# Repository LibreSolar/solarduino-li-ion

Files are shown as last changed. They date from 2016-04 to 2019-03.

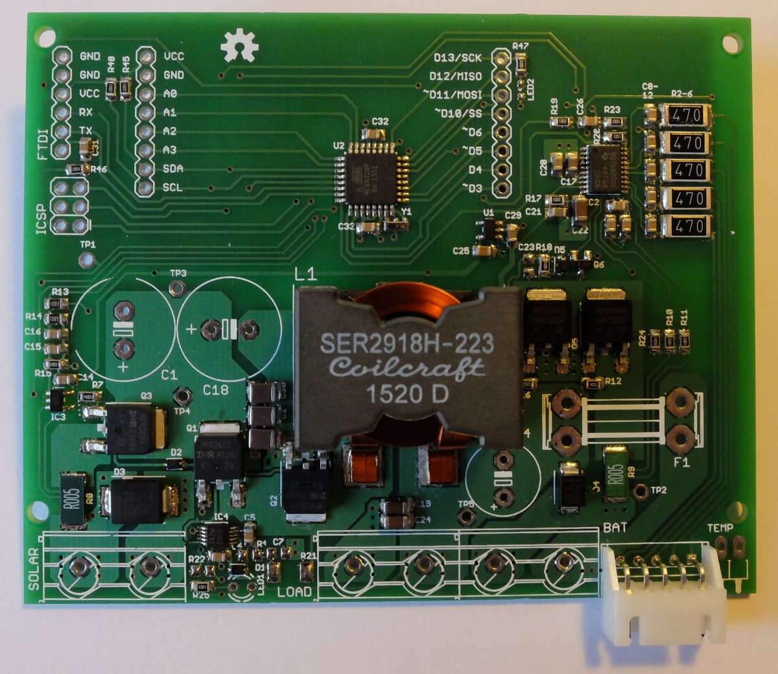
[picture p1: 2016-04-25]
DSCF9015_small.jpg

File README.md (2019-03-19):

# Solarduino Li-Ion
Solar charge controller with integrated 12 V Li-Ion BMS

**Remark:** This charge controller is not maintained anymore and firmware + hardware might contain serious bugs. Use at your own risk!

Features so far: 

- 12 V LiFePO4 BMS (4 cells)
- 8A MPPT charger
- 50V max PV input
- 16V max. DCDC output = battery voltage
- Arduino-compatible (ATmega 328P used)
- Expandable via break-out of unused ports to standard 2.54 pin-pitch headers (e.g. used for display, communication like CAN/RS485, etc.)

Built-in protection:
- Overvoltage
- Undervoltage
- Overcurrent
- Overtemperature (via software)
- PV short circuit
- PV reverse polarity (via diode)
- Battery reverse polarity (destructive, fuse is blown)

# Firmware
The last version of the firmware based on Arduino can be found in the firmware directory.

# Known issues
- The current measurement using the INA168 does not work properly. The output should not be directly connected to the ADC, but should be buffed using an Op-amp in between.

# Roadmap
- My plan for the future is to separate the BMS system and the charge controller. Separate modules make the system more flexible. For a new, extended version of the BMS system see my other project here on github.
- A new version of the Solarduino charge controller will be capable of 12-24V and 12 A, thus just perfect for one large 60-cell PV panel in a 24V system.

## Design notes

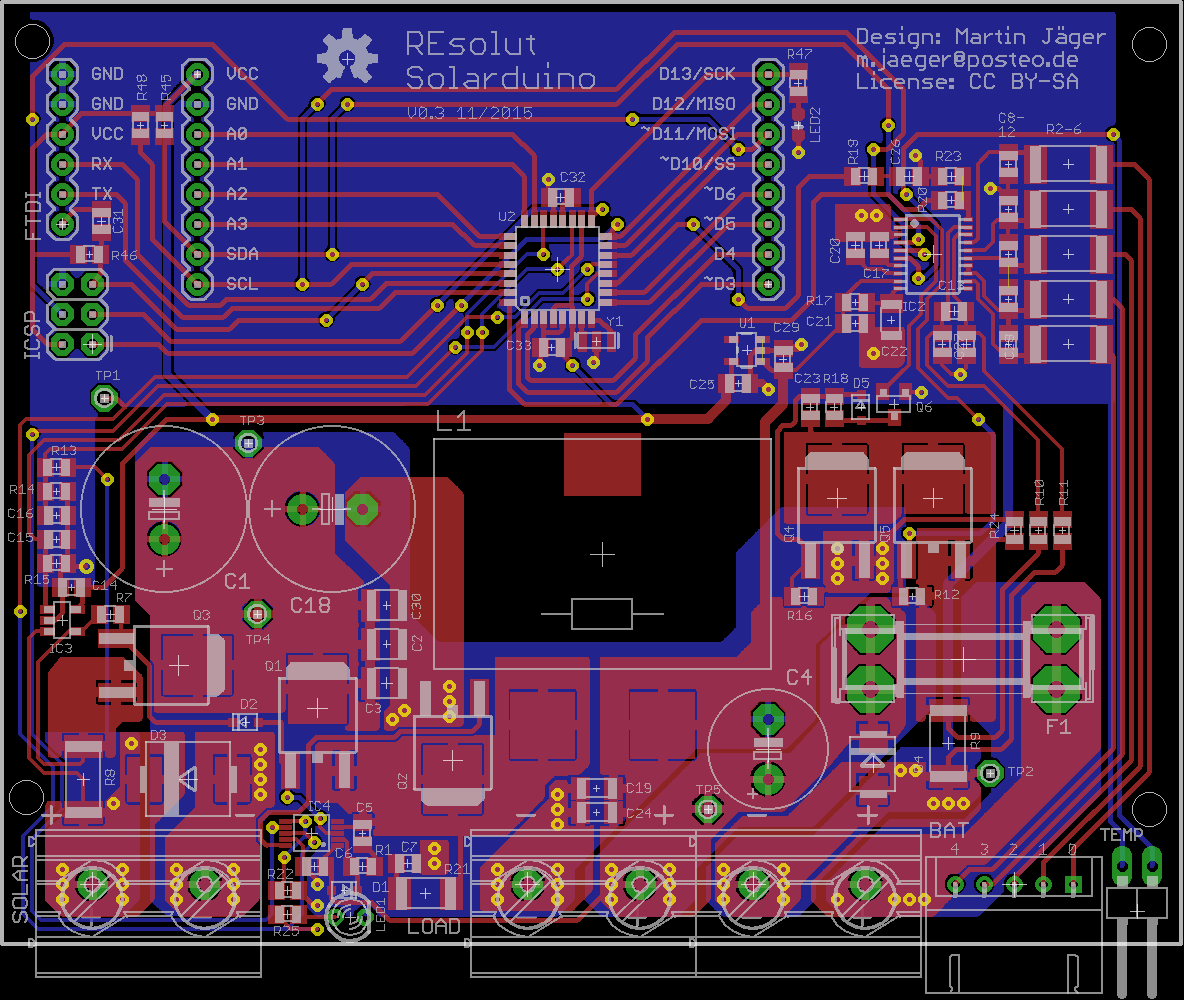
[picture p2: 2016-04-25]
Solarduino.png

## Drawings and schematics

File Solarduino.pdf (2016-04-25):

A

A

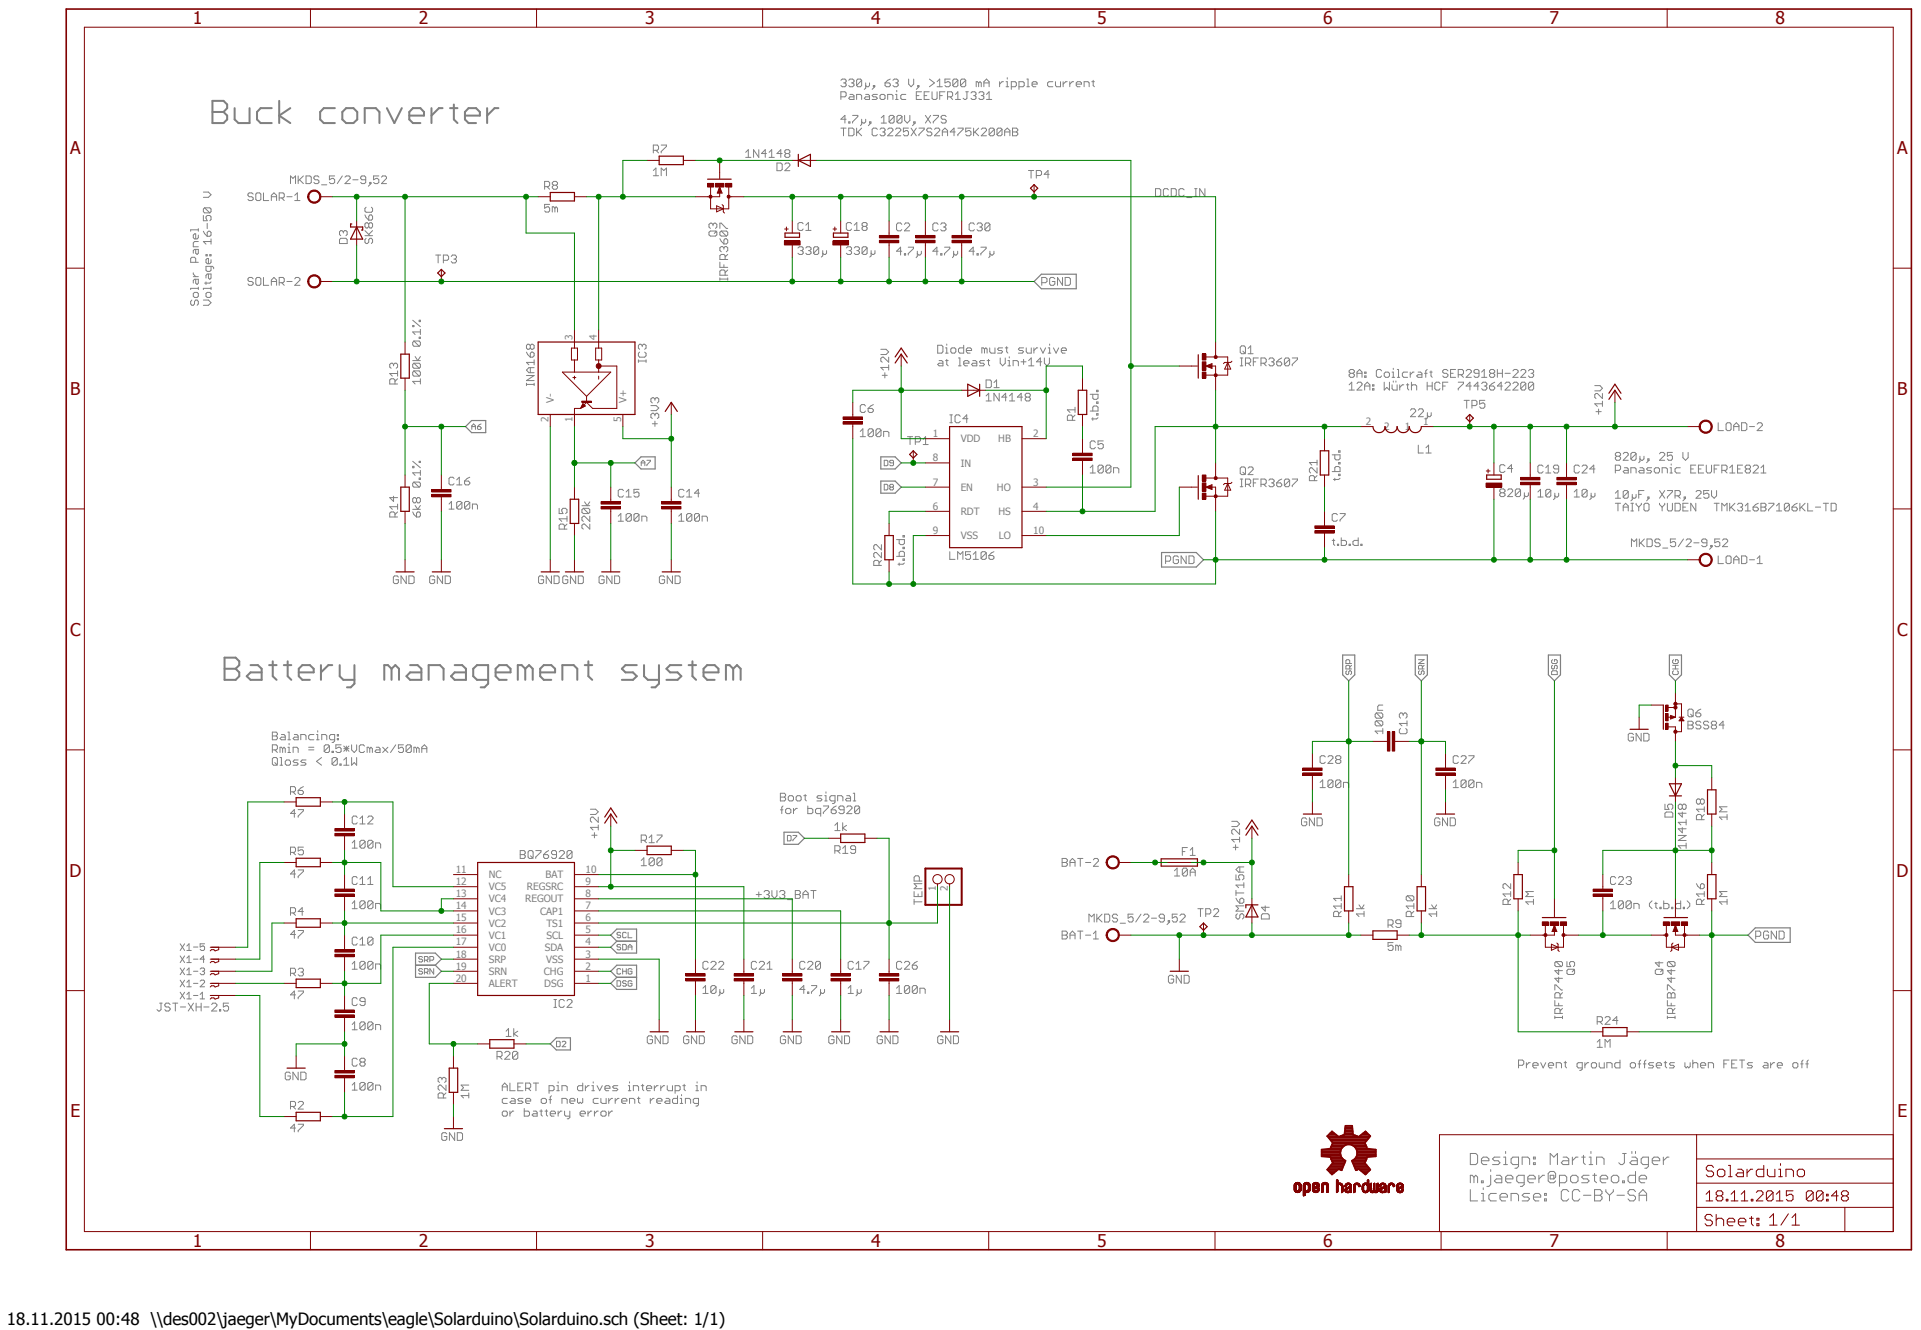
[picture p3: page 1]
DSG; 1 CHG; 2 VSS; 3 SDA; 4 SCL; 6 CAP1; 7 REGOUT; 8 REGSRC; 9 BAT; SRP 18; SRN 19; ALERT 20; VDD 1; 4 RDT 6; VSS 9

18.11.2015 00:48 \\des002\jaeger\MyDocuments\eagle\Solarduino\Solarduino.sch (Sheet: 1/1)

A

A

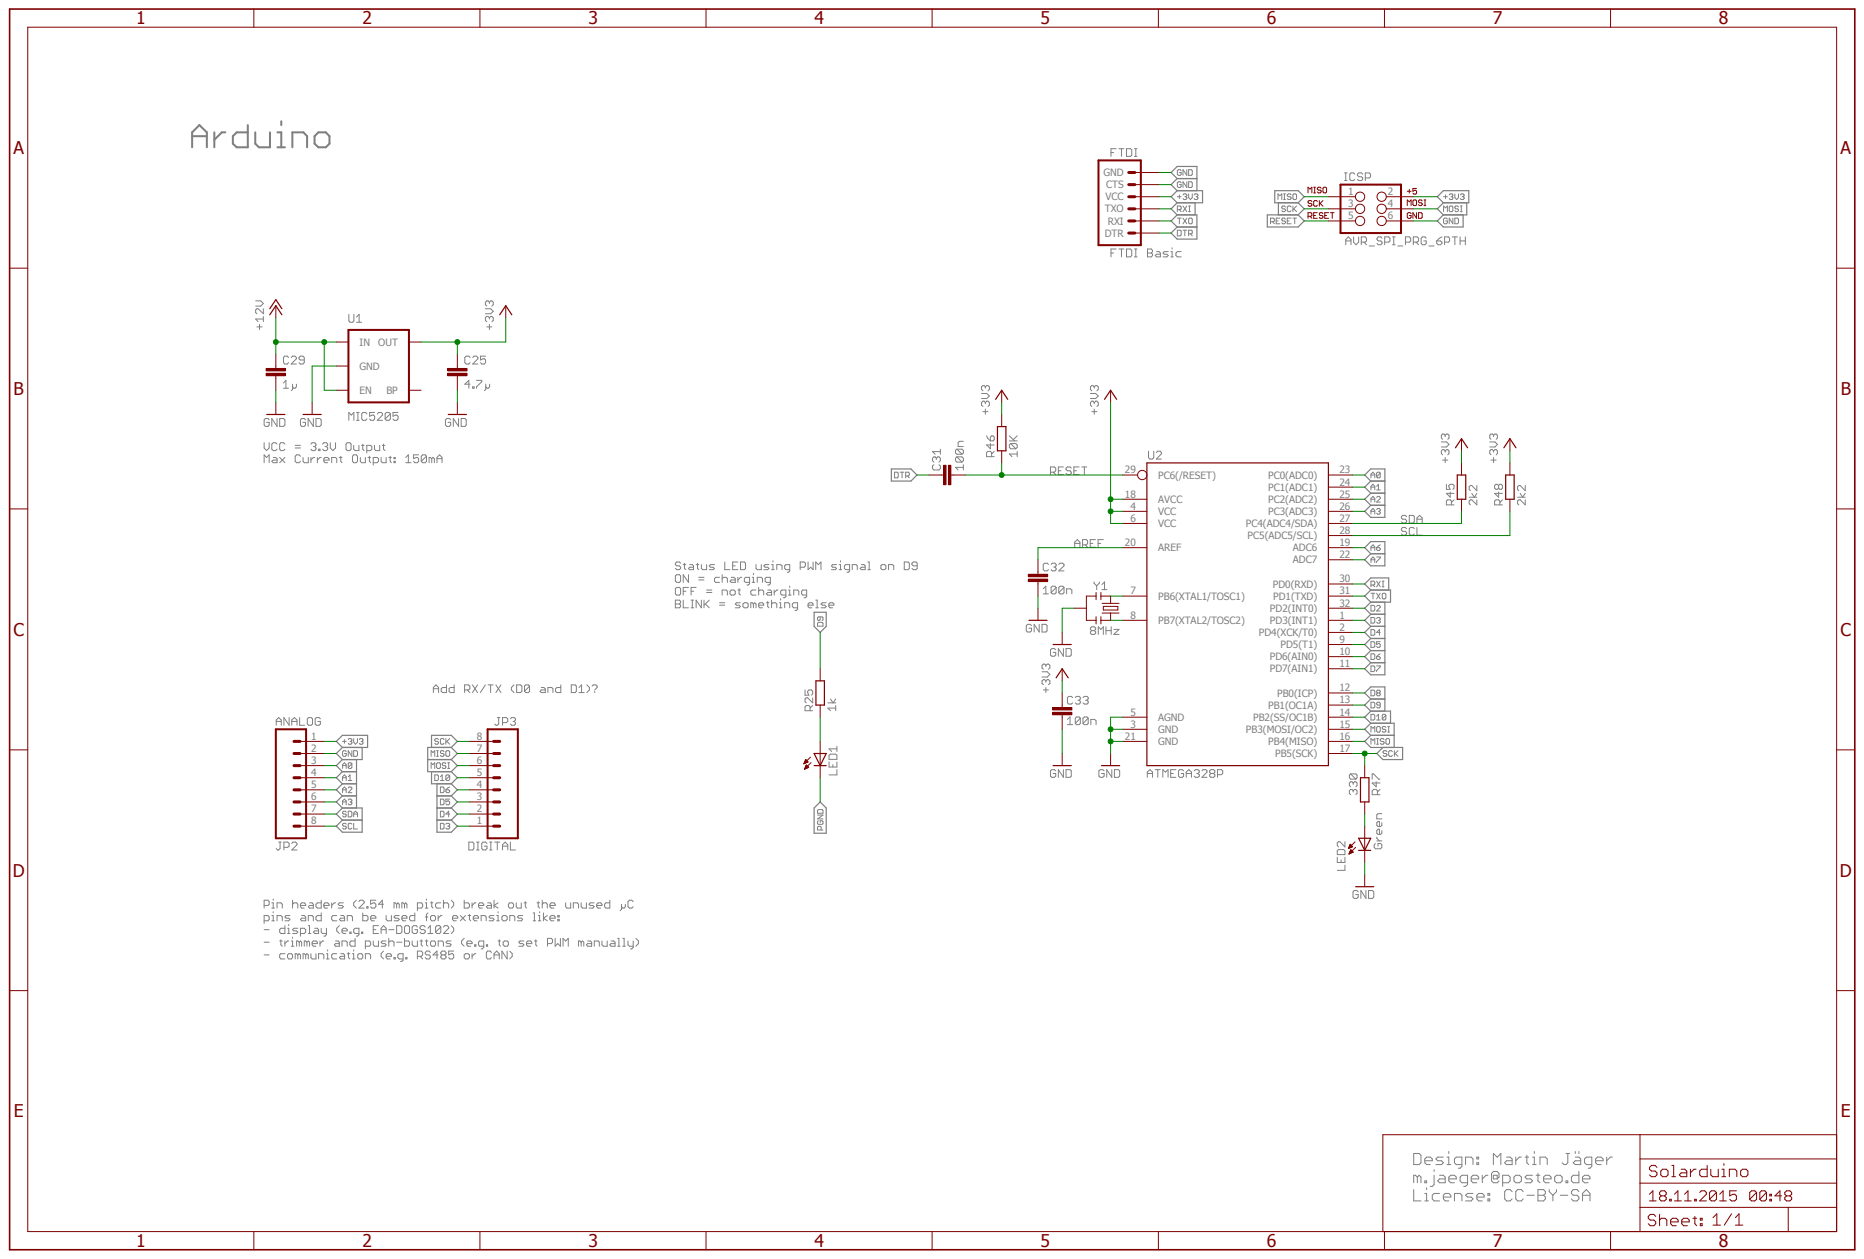
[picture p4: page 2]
PB5(SCK); PB7(XTAL2/TOSC2); PB6(XTAL1/TOSC1); GND; 3 GND 21; VCC; AGND; AREF 20; AVCC 18; PB4(MISO); 16 PB3(MOSI/OC2); 13 PB0(ICP); PD7(AIN1); 11 PD6(AIN0); 9 PD4(XCK/T0); 2 PD3(INT1); 1 PD2(INT0); 32 PD1(TXD); 31 PD0(RXD); ADC7; 22 ADC6; 19 PC5(ADC5/SCL); 28 PC4(ADC4/SDA); 27 PC3(ADC3); 26 PC2(ADC2); 25 PC1(ADC1); 24 PC0(ADC0); 23 PC6(/RESET) 29; DTR; RXI; TXO; CTS; OUT

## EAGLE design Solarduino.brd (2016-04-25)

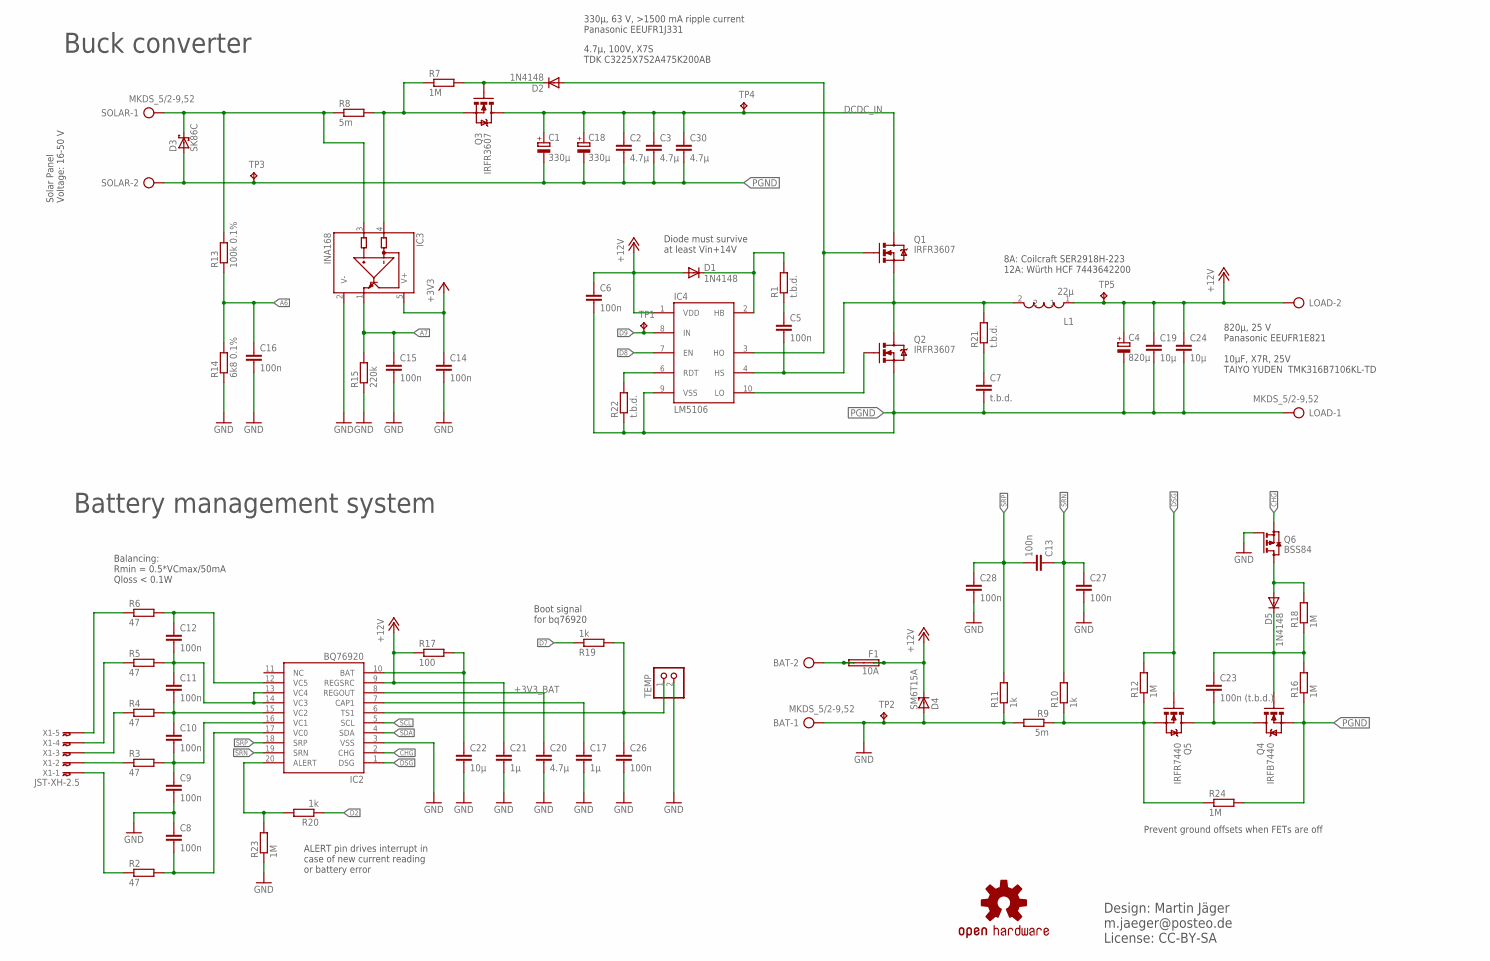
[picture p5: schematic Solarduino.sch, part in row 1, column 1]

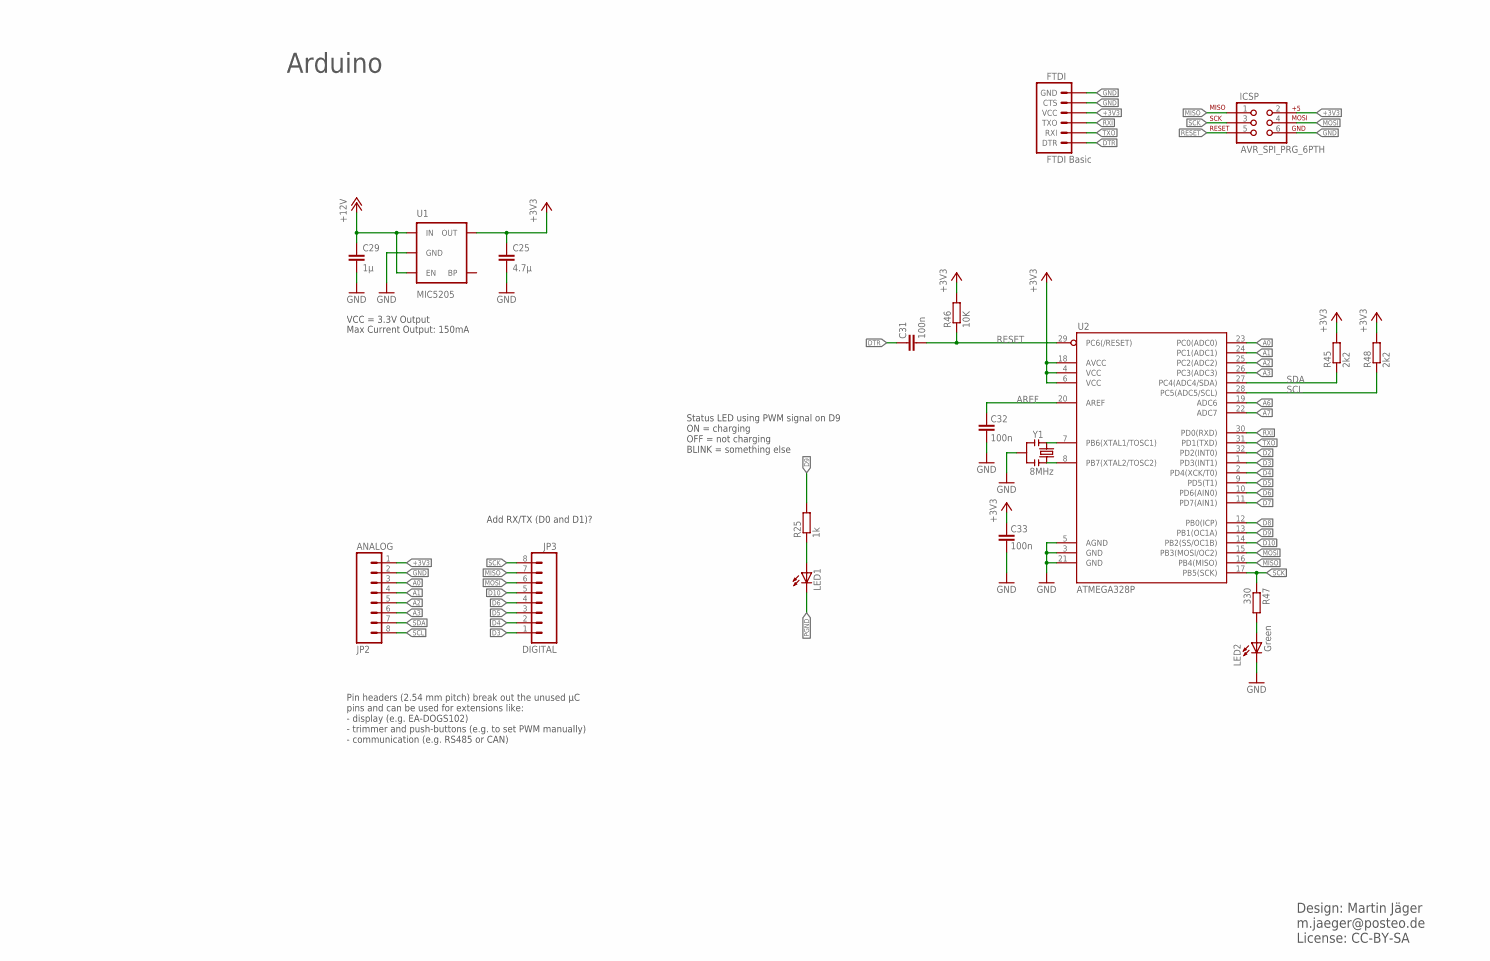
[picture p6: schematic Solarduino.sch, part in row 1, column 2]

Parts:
BAT: MKDS_5/2-9,52; MKDS_5/2-952
C1, C18: 330µ; E5-13; MPN EEUFR1J331B
C2, C3, C30: 4.7µ; C1210; MPN C3225X7S2A475K200AB
C4: 820µ; E5-10,5; MPN EEUFR1E821B
C5, C6, C8, C9, C10, C11, C12, C13, C14, C15, C16, C26, C27, C28, C31, C32: 100n; C0805; MPN 08055C104KAT2A
C7: t.b.d.; C0805; MPN 08055C104KAT2A
C17, C21, C29: 1µ; C0805; MPN 08053C105KAT2A
C19, C22, C24: 10µ; C1206; MPN TMK316B7106KL-TD
C20, C25: 4.7µ; C0805; MPN 0805YC475KAT2A
C23: 100n (t.b.d.); C0805; MPN 08055C104KAT2A
C33: 100n; C0805; MPN 08055C104JAT2A
D1, D2, D5: 1N4148; SOD323-R; MPN 1N4148WS-E3-08
D3: SK86C; SMC; MPN SK56C
D4: SM6T15A; SMB; MPN P6SMBJ15A
F1: 10A; SHK20Q
FTDI: FTDI Basic; 1X06; MPN 2212S-06SG-85
IC2: BQ76920; TSSOP20
IC3: INA168; SOT23-5; MPN INA168NA/250.
IC4: LM5106; VSSOP10; MPN LM5106MM/NOPB
ICSP: AVR_SPI_PRG_6PTH; 2X3
JP2: ANALOG; 1X08_ROUND
JP3: DIGITAL; 1X08_ROUND
L1: 22µ; WE-HCF_2818_7443643300; MPN SER2918H-223KL
LED1: LED3MM; MPN MCL034GD
LED2: Green; 0603-LED-ALT1; MPN MCL034GD
LOAD: MKDS_5/2-9,52; MKDS_5/2-952
N1: OSHW-LOGOM; OSHW-LOGO-M
Q1, Q2, Q3: IRFR3607; DPAK; MPN IRFR3607PBF
Q4: IRFB7440; DPAK; MPN IRFR7440TRPBF
Q5: IRFR7440; DPAK; MPN IRFR7440TRPBF
Q6: BSS84; SOT23; MPN BSS84-7-F
R1, R22: t.b.d.; R0805; MPN CR0805-FX-1001ELF
R2, R3, R4, R5, R6: 47; R2512; MPN MCHP122WF470JT4E
R7, R12, R16, R18, R23, R24: 1M; R0805; MPN CR0805-FX-1004ELF.
R8, R9: 5m; R2512; MPN CRF2512-FX-R005ELF
R10, R11, R19, R20, R25: 1k; R0805; MPN CR0805-FX-1001ELF
R13: 100k 0.1%; R0805; MPN ERA6AEB104V
R14: 6k8 0.1%; R0805; MPN ERA6AEB682V
R15: 220k; R0805; MPN CHV0805-FX-2203ELF
R17: 100; R0805; MPN CR0805-FX-1000-ELF
R21: t.b.d.; R2010; MPN CRM2010-JW-2R2ELF
R45, R48: 2k2; R0805; MPN CR0805-FX-1001ELF
R46: 10K; R0805; MPN CR0805-FX-1002ELF
R47: 330; R0805; MPN CR0805-FX-3300ELF
SOLAR: MKDS_5/2-9,52; MKDS_5/2-952
TEMP: PINHD-1X2/90; 1X02/90; MPN MC34745
TP1, TP2, TP3, TP4, TP5: TPPAD1-13; P1-13
U1: MIC5205; SOT23-5; MPN MIC5205-3.3YM5 TR
U2: ATMEGA328P; TQFP32-08; MPN ATMEGA328P-AU
X1: JST-XH-2.5; S5B-XH; MPN S5B-XH-A (LF)(SN)
Y1: 8MHz; RESONATOR-SMD; MPN CSTCE8M00G55-R0

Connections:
+3V3: C14.1, C25.1, C33.2, FTDI.4 (VCC), IC3.5 (V+), ICSP.2, JP2.1, R45.2, R46.2, R48.2, U1.5 (OUT), U2.4 (VCC), U2.6 (VCC), U2.18 (AVCC)
+3V3_BAT: C20.1, IC2.8 (REGOUT)
+12V: C4.+, C6.1, C19.1, C21.1, C24.1, C29.1, D1.A, D4.C, F1.1A, F1.1B, IC2.9 (REGSRC), IC4.1 (VDD), L1.1, LOAD.2, R17.1, TP5.TP, U1.1 (IN), U1.3 (EN)
A0: JP2.3, U2.23 (PC0(ADC0))
A1: JP2.4, U2.24 (PC1(ADC1))
A2: JP2.5, U2.25 (PC2(ADC2))
A3: JP2.6, U2.26 (PC3(ADC3))
A6: C16.1, R13.1, R14.2, U2.19 (ADC6)
A7: C15.1, IC3.1 (OUT), R15.2, U2.22 (ADC7)
ALERT: IC2.20 (ALERT), R20.2, R23.2
AREF: C32.2, U2.20 (AREF)
BAT+: BAT.2, F1.2A, F1.2B
CHG: IC2.2 (CHG), Q6.2 (S)
D2: R20.1, U2.32 (PD2(INT0))
D3: JP3.1, U2.1 (PD3(INT1))
D4: JP3.2, U2.2 (PD4(XCK/T0))
D5: JP3.3, U2.9 (PD5(T1))
D6: JP3.4, U2.10 (PD6(AIN0))
D7: R19.1, U2.11 (PD7(AIN1))
D8: IC4.7 (EN), U2.12 (PB0(ICP))
D9: IC4.8 (IN), R25.2, TP1.TP, U2.13 (PB1(OC1A))
D10: JP3.5, U2.14 (PB2(SS/OC1B))
DCDC_IN: C1.+, C2.1, C3.1, C18.+, C30.1, Q1.4 (D), Q3.4 (D), TP4.TP
DSG: IC2.1 (DSG), Q5.1 (G), R12.2
DTR: C31.2, FTDI.1 (DTR)
D_LS: C5.2, IC4.4 (HS), L1.2, Q1.3 (S), Q2.4 (D), R21.2
GND: BAT.1, C8.1, C9.2, C14.2, C15.2, C16.2, C17.2, C20.2, C21.2, C22.2, C25.2, C26.2, C27.2, C28.2, C29.2, C32.1, C33.1, D4.A, FTDI.5 (CTS), FTDI.6 (GND), IC2.3 (VSS), IC3.2 (V-), ICSP.6, JP2.2, LED2.C, Q6.1 (G), R9.2, R11.1, R14.1, R15.1, R23.1, TEMP.2, TP2.TP, U1.2 (GND), U2.3 (GND), U2.5 (AGND), U2.21 (GND), Y1.2
MISO: ICSP.1, JP3.7, U2.16 (PB4(MISO))
MOSI: ICSP.4, JP3.6, U2.15 (PB3(MOSI/OC2))
unnamed: IC3.4 (IN-), Q3.3 (S), R7.1, R8.2
unnamed: IC4.10 (LO), Q2.1 (G)
unnamed: LED2.A, R47.2
unnamed: D2.A, IC4.3 (HO), Q1.1 (G)
unnamed: D1.C, IC4.2 (HB), R1.2
unnamed: C23.1, D5.C, Q4.1 (G), R16.2, R18.1
unnamed: R3.1, X1.P$2
unnamed: C5.1, R1.1
unnamed: C22.1, IC2.10 (BAT), R17.2
unnamed: C10.1, C11.2, IC2.15 (VC2), R4.2
unnamed: C11.1, C12.2, IC2.13 (VC4), IC2.14 (VC3), R5.2
unnamed: R2.1, X1.P$1
unnamed: C12.1, IC2.12 (VC5), R6.2
unnamed: C8.2, IC2.17 (VC0), R2.2
unnamed: R4.1, X1.P$3
unnamed: C9.1, C10.2, IC2.16 (VC1), R3.2
unnamed: R5.1, X1.P$4
unnamed: D5.A, Q6.3 (D), R18.2
unnamed: D2.C, Q3.1 (G), R7.2
unnamed: U2.8 (PB7(XTAL2/TOSC2)), Y1.3
unnamed: U2.7 (PB6(XTAL1/TOSC1)), Y1.1
unnamed: Q5.3 (S), R9.1, R10.1, R12.1, R24.1
unnamed: C23.2, Q4.4 (D), Q5.4 (D)
unnamed: IC4.6 (RDT), R22.2
unnamed: R6.1, X1.P$5
unnamed: C17.1, IC2.7 (CAP1)
unnamed: C7.1, R21.1
unnamed: LED1.A, R25.1
NTC: C26.1, IC2.6 (TS1), R19.2, TEMP.1
PGND: C1.-, C2.2, C3.2, C4.-, C6.2, C7.2, C18.-, C19.2, C24.2, C30.2, D3.A, IC4.9 (VSS), LED1.K (C), LOAD.1, Q2.3 (S), Q4.3 (S), R16.1, R22.1, R24.2, SOLAR.2, TP3.TP
RESET: C31.1, ICSP.5, R46.1, U2.29 (PC6(/RESET))
RXI: FTDI.3 (TXO), U2.30 (PD0(RXD))
SCK: ICSP.3, JP3.8, R47.1, U2.17 (PB5(SCK))
SCL: IC2.5 (SCL), JP2.8, R48.1, U2.28 (PC5(ADC5/SCL))
SDA: IC2.4 (SDA), JP2.7, R45.1, U2.27 (PC4(ADC4/SDA))
SOLAR+: D3.C, IC3.3 (IN+), R8.1, R13.2, SOLAR.1
SRN: C13.1, C27.1, IC2.19 (SRN), R10.2
SRP: C13.2, C28.1, IC2.18 (SRP), R11.2
TXO: FTDI.2 (RXI), U2.31 (PD1(TXD))

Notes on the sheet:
330µ, 63 V, >1500 mA ripple current Panasonic EEUFR1J331
820µ, 25 V Panasonic EEUFR1E821 10µF, X7R, 25V TAIYO YUDEN TMK316B7106KL-TD
Balancing: Rmin = 0.5*VCmax/50mA Qloss < 0.1W
Solar Panel Voltage: 16-50 V
Diode must survive at least Vin+14V
Arduino
Add RX/TX (D0 and D1)?
Boot signal for bq76920
ALERT pin drives interrupt in case of new current reading or battery error
Max Current Output: 150mA
VCC = 3.3V Output
Pin headers (2.54 mm pitch) break out the unused µC pins and can be used for extensions like: - display (e.g. EA-DOGS102) - trimmer and push-buttons (e.g. to set PWM manually) - communication (e.g. RS485 or CAN)
Design: Martin Jäger m.jaeger@posteo.de License: CC-BY-SA
Buck converter
Battery management system
Prevent ground offsets when FETs are off
4.7µ, 100V, X7S TDK C3225X7S2A475K200AB
Status LED using PWM signal on D9 ON = charging OFF = not charging BLINK = something else
8A: Coilcraft SER2918H-223 12A: Würth HCF 7443642200

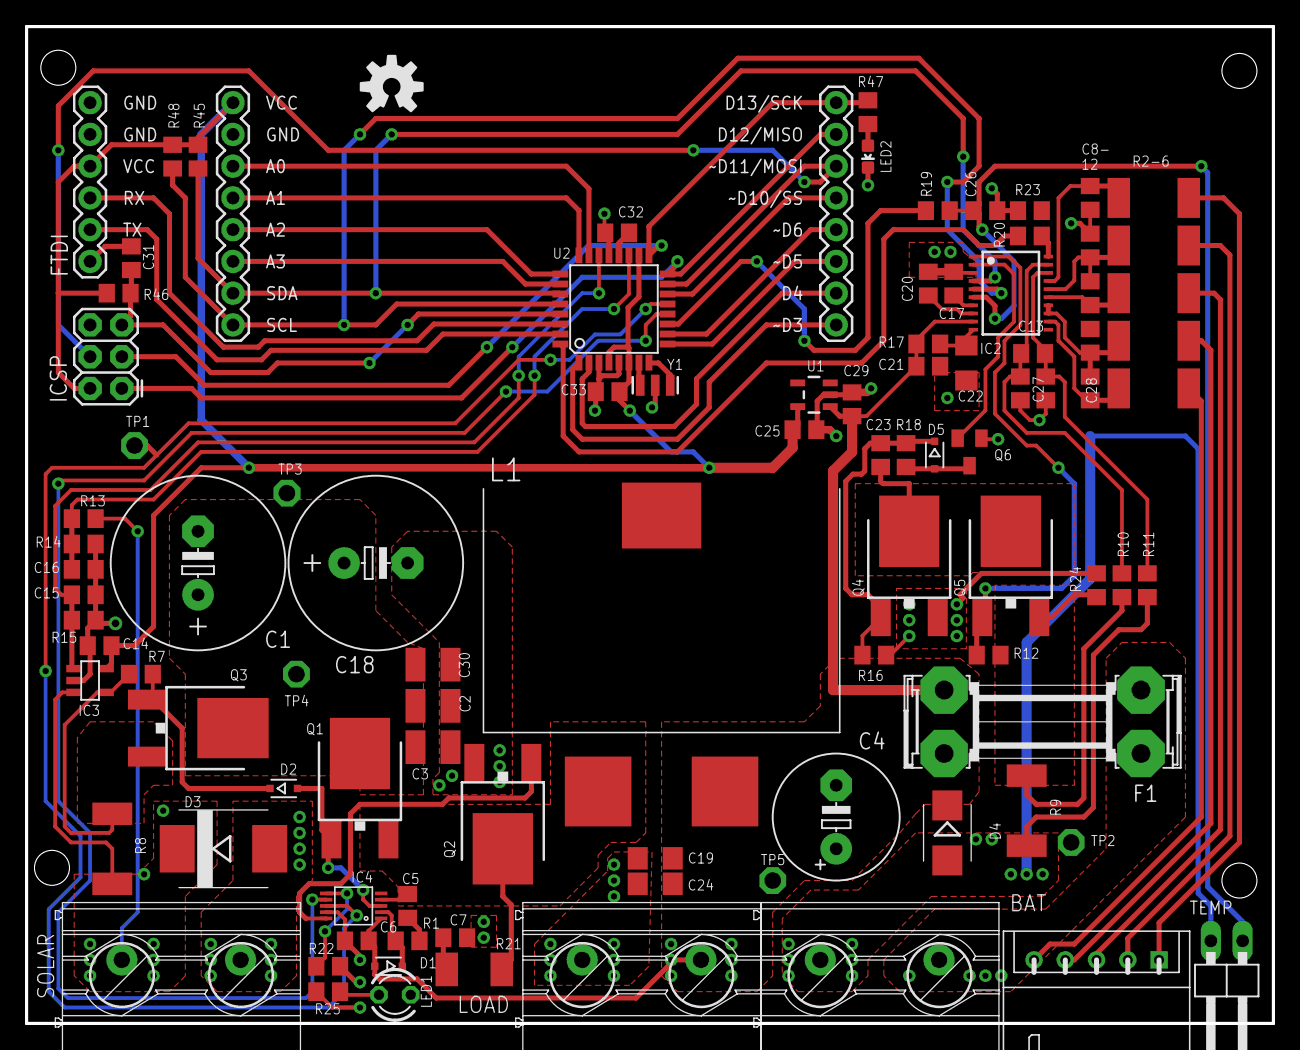
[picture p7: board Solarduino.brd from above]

Board: 2 copper layers, 99.7 x 79.7 mm, 98 parts (0 on the bottom side), 68 nets.

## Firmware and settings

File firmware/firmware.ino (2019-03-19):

/**
 *  Solarduino Software
 *  Martin Jäger, 2015
 *
 *  Solar charger and integrated LiFePO battery management system
 *  - uC: ATmega 328P with Arduino compatible pin useage
 *  - BMS IC: Texas Instruments bq76920
 *  - MPPT solar charger: Buck converter, max. 8A output current
 *
 *  
 */

//----------------------------------------------------------------------------
// includes

#include <Arduino.h>
#include <Wire.h>     // I2C/TWI (for Battery Management IC)
#include <SPI.h>      // SPI (for Display)
#include "helper.h"   // helper functions

#include <bq769x0.h>    // Library for Texas Instruments bq76920 battery management IC

// Display
#include <dog_1701.h>
#include <font_16x32nums.h>
#include <font_6x8.h>
#include <font_8x16.h>
#include <font_8x8.h>

//----------------------------------------------------------------------------
// definitions

#define PWM_PIN 9           // PWM input of half bridge driver
#define PWM_ENABLE_PIN 8    // enable pin of half bridge driver
#define DISP_CS_PIN    10
#define DISP_CD_PIN    A1
#define DISP_RESET_PIN A0
#define SOLAR_VOLTAGE_PIN A6
#define SOLAR_CURRENT_PIN A7

#define BMS_ALERT_PIN 2     // attached to interrupt INT0
#define BMS_BOOT_PIN 7      // connected to TS1 input
#define BMS_I2C_ADDRESS 0x18

// DC/DC converter settings
//
// The PWM resolution (number of steps between 0 and 100%) is limited by the
// µC frequency and the used PWM mode
// 8 MHz µC frequency and 100 kHz PWM frequency: 80 steps
//
#define PWM_FREQUENCY 100 // kHz
#define PWM_RESOLUTION ((F_CPU/1000)/PWM_FREQUENCY)
#define PWM_MIN (60.0/100.0*PWM_RESOLUTION)     // defines maximum input voltage (D=Vout/Vin)
#define PWM_INC 1                             // PWM increment for MPP tracking

#define MIN_SOLAR_CURRENT 50  // mA    --> if lower, charger is switched off
#define SOLAR_VOLTAGE_OFFSET 2000 // mV  charging switched on if Vsolar > Vbat + offset

// misc
#define ON 1
#define OFF 0
#define NUM_AVG 10    // number of ADC values to read for averaging

#define TURN_ON_MOSFETS digitalWrite(PWM_ENABLE_PIN, HIGH)      // enable MOSFET driver
#define TURN_OFF_MOSFETS digitalWrite(PWM_ENABLE_PIN, LOW)      // disable MOSFET driver

#define CUTOFF_VOLTAGE_CHG 3550  // mV    recommended value for ECC 45 Ah: 3550
#define CUTOFF_VOLTAGE_DSG 3000  // mV    recommended value for ECC 45 Ah: 3000
#define MAX_CHG_CURRENT 8000  // mA       PCB maximum: 8 A

//----------------------------------------------------------------------------
// global variables

dog_1701 DOG;   // display object
bq769x0 BMS(bq76920, BMS_I2C_ADDRESS);    // battery management system object

int pwm_duty = 63;  // PWM duty cycle (= PWM_RESOLUTION - 1 for 100%)
int solar_voltage;      // mV
int solar_current;      // mA

long solar_voltage_total;
long solar_current_total;
int solar_voltage_readings[NUM_AVG];
int solar_current_readings[NUM_AVG];
int i_readings = 0;

unsigned int solar_power_prev = 0;   // unit: 1/100 W
unsigned int solar_power = 0;        // unit: 1/100 W
int pwm_delta = PWM_INC;    // variable used to modify pwm duty cycle for the MPPT algorithm

enum charger_states {STANDBY, CHG_CC, CHG_CV, BAT_ERROR, BALANCING};     // enumerated variable that holds state for charger state machine
int state = BAT_ERROR;


//----------------------------------------------------------------------------
void setup()
{
  Serial.begin(9600);  // start serial for output  

  int err = BMS.begin(BMS_ALERT_PIN, BMS_BOOT_PIN);

  // ToDo: Ensure that these settings are set even in case of initial communication error
  BMS.setTemperatureLimits(-20, 45, 0, 45);
  BMS.setShuntResistorValue(5);
  BMS.setShortCircuitProtection(14000, 200);  // delay in us
  BMS.setOvercurrentChargeProtection(8000, 200);  // delay in ms
  BMS.setOvercurrentDischargeProtection(8000, 320); // delay in ms
  BMS.setCellUndervoltageProtection(2600, 2); // delay in s
  BMS.setCellOvervoltageProtection(3650, 2);  // delay in s

  BMS.setBalancingThresholds(0, 3300, 20);  // minIdleTime_min, minCellV_mV, maxVoltageDiff_mV
  BMS.setIdleCurrentThreshold(100);
  BMS.enableAutoBalancing();
  BMS.enableDischarging();
/*
  if (err > 0) {
    enter_state(BAT_ERROR);
  }
  else {
    enter_state(STANDBY);
  }
  */
  //initPWM();
  // TEST BEGIN
  pinMode(PWM_PIN, OUTPUT);
  pinMode(PWM_ENABLE_PIN, OUTPUT);
  digitalWrite(PWM_ENABLE_PIN, HIGH);
  Serial.println("PWM PIN is now highg");
  // TEST END
  
  // display
  DOG.initialize(DISP_CS_PIN, 0, 0, DISP_CD_PIN, DISP_RESET_PIN, DOGS102); // 0,0 = Hardware SPI, EA DOGS102-6 (=102x64 dots)
  //DOG.initialize(DISP_CS_PIN, 11, 13, DISP_CD_PIN, DISP_RESET_PIN, DOGS102); // 0,0 = Hardware SPI, EA DOGS102-6 (=102x64 dots)
  DOG.view(VIEW_BOTTOM);  //default viewing direction

  // initialize variables with zeros
  for (int i = 0; i < NUM_AVG; i++) {
    solar_voltage_readings[i] = 0;
    solar_current_readings[i] = 0;
  }
}

//----------------------------------------------------------------------------
// Sets Timer1 to run PWM output at Arduino pin 9
// 
void initPWM()
{
  // PWM_PIN must be pin 9 (OC1A of ATmega328P)
  pinMode(PWM_PIN, OUTPUT);
  pinMode(PWM_ENABLE_PIN, OUTPUT);

  // set mode 14: Fast PWM, TOP stored in ICR1
  TCCR1A = _BV(WGM11);
  TCCR1B = _BV(WGM13) | _BV(WGM12);
  
  // no prescaling
  TCCR1B |= _BV(CS10);

  // disable interrupts for 16-bit register access
  unsigned char sreg;  
  sreg = SREG;  // Save global interrupt flag
  cli();        // Disable interrupts

  // set TOP to define PWM frequency
  ICR1 = PWM_RESOLUTION - 1;
  
  SREG = sreg;  // Restore global interrupt flag

  Serial.print("PWM cycles: ");
  Serial.println(PWM_RESOLUTION);
}

//----------------------------------------------------------------------------
void loop()
{

  BMS.update();  // should be called at least every 250 ms

  update_solar_power();
  //state_machine();
  update_screen();
  
  //print_status();
  
  //BMS.printRegisters();

  // TEST BEGIN
  //TURN_ON_MOSFETS;
  //enter_state(CHG_CC);
  // TEST END
  
  /*
  // PWM testing
  char incoming = 0; 
  if (Serial.available() > 0) {
    // read the incoming byte:
    incoming = Serial.read();

    if (incoming == '+') {
      pwm_duty++;
      set_pwm_duty();
    }
    else if (incoming == '-') {
      pwm_duty--;
      set_pwm_duty();
    }
    
    Serial.print("PWM: ");
    Serial.print(pwm_duty);
    Serial.print("      Solar Power [mA]: ");
    Serial.println(solar_power);
  }

*/
  delay(100);
}

// actions to be performed upon entering a state
void enter_state(int next_state)
{
  switch (next_state)
  {
    case STANDBY:
      Serial.println(F("Enter State: STANDBY"));
      TURN_OFF_MOSFETS; 
      if (BMS.enableDischarging() == false) {
        return;
      }
      break;
    case CHG_CC:
      Serial.println(F("Enter State: CHG_CC"));
      if (BMS.enableCharging() == true)
      {
        //pwm_duty = PWM_RESOLUTION * BMS.getBatteryVoltage() / solar_voltage + 1;  // start with proper PWM duty cycle
        pwm_delta = -PWM_INC;
        set_pwm_duty();
        TURN_ON_MOSFETS;
        Serial.println(F("OK, laden muesste jetzt laufen..."));
      }
      else {
        Serial.println("Laden nicht möglich!");
        return;   // charging not possible
      }
      break;
    case CHG_CV:
      Serial.println("Enter State: CHG_CV");
      // coming from CHG_CC --> DC/DC FETs already on and charging enabled
      break;
    case BAT_ERROR:
      Serial.println("Enter State: BAT_ERROR");
      TURN_OFF_MOSFETS;
      break;
    case BALANCING:
      Serial.println("Enter State: BALANCING");
      TURN_OFF_MOSFETS; 
      break;
    default:
      TURN_OFF_MOSFETS; 
      break;
  }
  state = next_state;
}

/*****************************************************************************
 *  Charger state machine
 *
 *  INIT       Initial state when system boots up. Checks communication to BMS
 *             and turns the CHG and DSG FETs on
 *  STANDBY    Battery can be discharged, but no charging power is available
 *             or battery is fully charged
 *  CHG_CC     Constant current (CC) charging with maximum current possible
 *             (MPPT algorithm is running)
 *  CHG_CV     Constant voltage (CV) charging at maximum cell voltage
 *  BAT_ERROR  An error occured. Charging disabled.
 *  BALANCING  After a period of no load in STANDBY state, balancing is 
 *             started. Goes back to STANDBY as soon as a load is detected.
 */
void state_machine()
{
  int err = 0;
  
  switch (state)
  {
    case STANDBY:
      if (BMS.checkStatus() == 0)
      {
        //Serial.println("Standby");
        if  ((solar_voltage > BMS.getBatteryVoltage() + SOLAR_VOLTAGE_OFFSET)) {      
          enter_state(CHG_CC);
        }
      }
      /*else if (BMS.balancingAllowed() == true)
      {
        enter_state(BALANCING);
      }*/
      break;
      
    case CHG_CC:
      if (BMS.checkStatus() == 0)
      {
        //Serial.println("CHG_CC state still alive");
        if (BMS.getMaxCellVoltage() > CUTOFF_VOLTAGE_CHG)
        {
          enter_state(CHG_CV);
        }/*
        else if (BMS.getBatteryCurrent() > MAX_CHG_CURRENT)
        {
          // increase PV voltage
          pwm_duty--;
          pwm_delta = -PWM_INC;
          set_pwm_duty();
          solar_power_prev = solar_power;
        }
        else // start MPPT
        {
          if (solar_power_prev > solar_power)
          {
            pwm_delta = -pwm_delta;
          }
          pwm_duty += pwm_delta;
          set_pwm_duty();
          solar_power_prev = solar_power;
        }*/      
      }
      else
      {
        enter_state(BAT_ERROR);
      }
      break;
      
    case CHG_CV:
      if (BMS.checkStatus() == 0)
      {
        if (solar_current < MIN_SOLAR_CURRENT)
        {
          enter_state(STANDBY);
          return;
        }
        else {
          if (BMS.getMaxCellVoltage() > CUTOFF_VOLTAGE_CHG)
          {
            // increase input voltage and decrease PV current
            pwm_duty--;
            set_pwm_duty();
          }
          else
          {
            pwm_duty++;
            set_pwm_duty();
          }
        }
      }
      else {
        enter_state(BAT_ERROR);
      }
      break;
      
    case BAT_ERROR:
      err = BMS.checkStatus();
      if (err == 0) {
        enter_state(STANDBY);
      }
      break;
      
    default:
      TURN_OFF_MOSFETS; 
      break;
  }
}

//----------------------------------------------------------------------------
void set_pwm_duty()
{
  if (pwm_duty >= PWM_RESOLUTION - 1)
  {
    pwm_duty = PWM_RESOLUTION - 2;            // 100% not possible because of charge pump
  }
  else if (pwm_duty < PWM_MIN)
  {       
    pwm_duty = PWM_MIN;
  }
  
  // disable interrupts for 16-bit register access
  unsigned char sreg = SREG;
  cli();

  // set
  OCR1A = pwm_duty;
  
  // restore global interrupt flag
  SREG = sreg;                  

  // Compare Output Mode: Fast PWM, non-inverting mode
  TCCR1A |= _BV(COM1A1);
  
  //Serial.print("PWM duty cycle: ");
  //Serial.println((pwm_duty+1.0)/(PWM_RESOLUTION) * 100.0);
}

//----------------------------------------------------------------------------
//create a sample sceen content
void update_screen(void)
{
  char str[20];
  char buf[20];
  
  DOG.clear();  //clear whole display
  //DOG.string(71,0,font_8x16,"DOGS");      //font size 8x16 first page         
  //DOG.rectangle(71,2,127,2,0x03);         //show small line (filled pattern = 0x03), to the left and right of 'DOGL128'            
  
  format_double(solar_voltage/1000.0, 2, buf, 20);
  sprintf(str, "Sol: %sV", buf);
  DOG.string(0,0,font_6x8, str);

  format_double(solar_current/1000.0, 2, buf, 20);
  sprintf(str, "%sA", buf);
  DOG.string(12*6,0,font_6x8, str);
  
  format_double(BMS.getBatteryVoltage()/1000.0, 2, buf, 20);
  sprintf(str, "Bat: %sV", buf);
  DOG.string(0,1,font_6x8, str);

  format_double(BMS.getBatteryCurrent()/1000.0, 2, buf, 20);
  sprintf(str, "%sA", buf);
  DOG.string(12*6,1,font_6x8, str);

  format_double(BMS.getTemperatureDegC(), 1, buf, 20);
  sprintf(str, "Temp: %s C", buf);
  DOG.string(0,2,font_6x8, str);
  
  format_double(solar_power/100.0, 2, buf, 20);
  sprintf(str, "Power: %s W", buf);
  DOG.string(0,3,font_6x8, str);
  
  format_double((pwm_duty+1.0)/(PWM_RESOLUTION) * 100.0, 2, buf, 20);
  sprintf(str, "PWM duty: %s %%", buf);
  DOG.string(0,4,font_6x8, str);
  
  DOG.string(0,5,font_6x8,"State:");
  switch (state)
  {
    case STANDBY:
      DOG.string(7*6,5,font_6x8,"Standby");
      break;
    case CHG_CC:
      DOG.string(7*6,5,font_6x8,"CC charge");
      break;
    case CHG_CV:
      DOG.string(7*6,5,font_6x8,"CV charge");
      break;
    case BAT_ERROR:
      byte sys_stat;
      sys_stat = BMS.checkStatus();
      if (sys_stat & B00100000)
        DOG.string(7*6,5,font_6x8,"XR Error");
      if (sys_stat & B00010000)
        DOG.string(7*6,5,font_6x8,"Alert Error");
      if (sys_stat & B00001000)
        DOG.string(7*6,5,font_6x8,"UV Error");
      if (sys_stat & B00000100)
        DOG.string(7*6,5,font_6x8,"OV Error");
      if (sys_stat & B00000010)
        DOG.string(7*6,5,font_6x8,"SCD Error");
      if (sys_stat & B00000001)
        DOG.string(7*6,5,font_6x8,"OCD Error");
      break;
    case BALANCING:
      DOG.string(7*6,5,font_6x8,"Balancing");
      break;    
  }

  format_double(BMS.getCellVoltage(1)/1000.0, 3, buf, 20);
  sprintf(str, "1:%sV", buf);
  DOG.string(0,6,font_6x8, str);

  format_double(BMS.getCellVoltage(2)/1000.0, 3, buf, 20);
  sprintf(str, "2:%sV", buf);
  DOG.string(51,6,font_6x8, str);
  
  format_double(BMS.getCellVoltage(3)/1000.0, 3, buf, 20);
  sprintf(str, "3:%sV", buf);
  DOG.string(0,7,font_6x8, str);

  format_double(BMS.getCellVoltage(5)/1000.0, 3, buf, 20);
  sprintf(str, "4:%sV", buf);
  DOG.string(51,7,font_6x8, str);
  
}

//----------------------------------------------------------------------------
// Print out current status of the system
void print_status(void)
{
  char str[20];
  char buf[20];
    
  format_double(solar_voltage/1000.0, 2, buf, 20);
  sprintf(str, "Sol: %sV ", buf);
  Serial.print(str);

  format_double(solar_current/1000.0, 2, buf, 20);
  sprintf(str, "%sA", buf);
  Serial.println(str);
  
  format_double(BMS.getBatteryVoltage()/1000.0, 2, buf, 20);
  sprintf(str, "Bat: %sV ", buf);
  Serial.print(str);

  format_double(BMS.getBatteryCurrent()/1000.0, 2, buf, 20);
  sprintf(str, "%sA", buf);
  Serial.println(str);

  format_double(BMS.getTemperatureDegC(), 1, buf, 20);
  sprintf(str, "Temp: %s °C", buf);
  Serial.println(str);
  
  format_double(solar_power/100.0, 2, buf, 20);
  sprintf(str, "Power: %s W", buf);
  Serial.println(str);
  
  format_double((pwm_duty+1.0)/(PWM_RESOLUTION) * 100.0, 2, buf, 20);
  sprintf(str, "PWM duty: %s %%", buf);
  Serial.println(str);
  
  Serial.print("State:");
  switch (state)
  {
    case STANDBY:
      Serial.println("Standby");
      break;
    case CHG_CC:
      Serial.println("CC charge");
      break;
    case CHG_CV:
      Serial.println("CV charge");
      break;
    case BAT_ERROR:
      byte sys_stat;
      sys_stat = BMS.checkStatus();
      if (sys_stat & B00100000)
        Serial.println("XR Error");
      if (sys_stat & B00010000)
        Serial.println("Alert Error");
      if (sys_stat & B00001000)
        Serial.println("UV Error");
      if (sys_stat & B00000100)
        Serial.println("OV Error");
      if (sys_stat & B00000010)
        Serial.println("SCD Error");
      if (sys_stat & B00000001)
        Serial.println("OCD Error");
      break;
    case BALANCING:
      Serial.println("Balancing");
      break;    
  }

  format_double(BMS.getCellVoltage(1)/1000.0, 3, buf, 20);
  sprintf(str, "1:%sV", buf);
  Serial.print(str);

  format_double(BMS.getCellVoltage(2)/1000.0, 3, buf, 20);
  sprintf(str, "  2:%sV", buf);
  Serial.print(str);
  
  format_double(BMS.getCellVoltage(3)/1000.0, 3, buf, 20);
  sprintf(str, "  3:%sV", buf);
  Serial.print(str);

  format_double(BMS.getCellVoltage(5)/1000.0, 3, buf, 20);
  sprintf(str, "  4:%sV", buf);
  Serial.println(str);
  
}

//----------------------------------------------------------------------------
int update_solar_power(void)
{
  int vcc;
  vcc = read_vcc();  // using internal reference voltage

  // subtract the last reading:
  solar_voltage_total -= solar_voltage_readings[i_readings];
  solar_current_total -= solar_current_readings[i_readings];

  // save new reading
  solar_voltage_readings[i_readings] = analogRead(SOLAR_VOLTAGE_PIN)/1023.0 * vcc * 106.8/6.8;  // mV
  
  // 220 kOhm resistor at INA168 --> gain 44
  // 5 mOhm shunt resistor
  solar_current_readings[i_readings] = analogRead(SOLAR_CURRENT_PIN)/1023.0 * vcc / 5.0 * 44;  // mA

  // add the reading to the total:
  solar_voltage_total += solar_voltage_readings[i_readings];
  solar_current_total += solar_current_readings[i_readings];
  
  i_readings++;
  if (i_readings >= NUM_AVG) {
    i_readings = 0;
  }

  solar_voltage = solar_voltage_total / NUM_AVG;
  solar_current = solar_current_total / NUM_AVG;

  solar_power = solar_voltage / 100.0 * solar_current / 100.0;
}

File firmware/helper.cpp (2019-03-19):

#include <Arduino.h>
#include "helper.h"

//
// Produce a formatted string in a buffer corresponding to the value provided.
// If the 'width' parameter is non-zero, the value will be padded with leading
// zeroes to achieve the specified width.  The number of characters added to
// the buffer (not including the null termination) is returned.
//
unsigned format_unsigned(unsigned long val, char *buf, unsigned bufLen, byte width)
{
  if (!buf || !bufLen)
    return(0);

  // produce the digit string (backwards in the digit buffer)
  char dbuf[10];
  unsigned idx = 0;
  while (idx < sizeof(dbuf))
  {
    dbuf[idx++] = (val % 10) + '0';
    if ((val /= 10) == 0)
      break;
  }

  // copy the optional leading zeroes and digits to the target buffer
  unsigned len = 0;
  byte padding = (width > idx) ? width - idx : 0;
  char c = '0';
  while ((--bufLen > 0) && (idx || padding))
  {
    if (padding)
      padding--;
    else
      c = dbuf[--idx];
    *buf++ = c;
    len++;
  }

  // add the null termination
  *buf = '\0';
  return(len);
}

//
// Format a floating point value with number of decimal places.
// The 'precision' parameter is a number from 0 to 6 indicating the desired decimal places.
// The 'buf' parameter points to a buffer to receive the formatted string.  This must be
// sufficiently large to contain the resulting string.  The buffer's length may be
// optionally specified.  If it is given, the maximum length of the generated string
// will be one less than the specified value.
//
// example: fmtDouble(3.1415, 2, buf); // produces 3.14 (two decimal places)
//
void format_double(double val, byte precision, char *buf, unsigned bufLen)
{
  if (!buf || !bufLen)
    return;

  // limit the precision to the maximum allowed value
  const byte maxPrecision = 6;
  if (precision > maxPrecision)
    precision = maxPrecision;

  if (--bufLen > 0)
  {
    // check for a negative value
    if (val < 0.0)
    {
      val = -val;
      *buf = '-';
      *buf++;
      bufLen--;
    }

    // compute the rounding factor and fractional multiplier
    double roundingFactor = 0.5;
    unsigned long mult = 1;
    for (byte i = 0; i < precision; i++)
    {
      roundingFactor /= 10.0;
      mult *= 10;
    }

    if (bufLen > 0)
    {
      // apply the rounding factor
      val += roundingFactor;

      // add the integral portion to the buffer
      unsigned len = format_unsigned((unsigned long)val, buf, bufLen);
      buf += len;
      bufLen -= len;
    }

    // handle the fractional portion
    if ((precision > 0) && (bufLen > 0))
    {
      *buf++ = '.';
      if (--bufLen > 0)
        buf += format_unsigned((unsigned long)((val - (unsigned long)val) * mult), buf, bufLen, precision);
    }
  }

  // null-terminate the string
  *buf = '\0';
}

//----------------------------------------------------------------------------
const char *byte2bin(int x)
{
    static char b[9];
    b[0] = '\0';

    int z;
    for (z = 128; z > 0; z >>= 1)
    {
        strcat(b, ((x & z) == z) ? "1" : "0");
    }

    return b;
}

//----------------------------------------------------------------------------
// Used for more accurate ADC readings
// Source: http://forum.arduino.cc/index.php?topic=133907.0
// 
long read_vcc()
{
  // Read 1.1V reference against AVcc
  // set the reference to Vcc and the measurement to the internal 1.1V reference
  #if defined(__AVR_ATmega32U4__) || defined(__AVR_ATmega1280__) || defined(__AVR_ATmega2560__)
    ADMUX = _BV(REFS0) | _BV(MUX4) | _BV(MUX3) | _BV(MUX2) | _BV(MUX1);
  #elif defined (__AVR_ATtiny24__) || defined(__AVR_ATtiny44__) || defined(__AVR_ATtiny84__)
    ADMUX = _BV(MUX5) | _BV(MUX0);
  #elif defined (__AVR_ATtiny25__) || defined(__AVR_ATtiny45__) || defined(__AVR_ATtiny85__)
    ADMUX = _BV(MUX3) | _BV(MUX2);
  #else
    ADMUX = _BV(REFS0) | _BV(MUX3) | _BV(MUX2) | _BV(MUX1);
  #endif  
 
  delay(2); // Wait for Vref to settle
  ADCSRA |= _BV(ADSC); // Start conversion
  while (bit_is_set(ADCSRA,ADSC)); // measuring
 
  uint8_t low  = ADCL; // must read ADCL first - it then locks ADCH  
  uint8_t high = ADCH; // unlocks both
 
  long result = (high<<8) | low;
 
  result = 1125300L / result; // Calculate Vcc (in mV); 1125300 = 1.1*1023*1000
  //Serial.print("VCC: ");
  //Serial.println(result);
  
  return result; // Vcc in millivolts
}

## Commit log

2016-04-25 Upload of board files V0.3
    [Solarduino.brd, Solarduino.sch]
2016-04-25 Added picture of soldered board

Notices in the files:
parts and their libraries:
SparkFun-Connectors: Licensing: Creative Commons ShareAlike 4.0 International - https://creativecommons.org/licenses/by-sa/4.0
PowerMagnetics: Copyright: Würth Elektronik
